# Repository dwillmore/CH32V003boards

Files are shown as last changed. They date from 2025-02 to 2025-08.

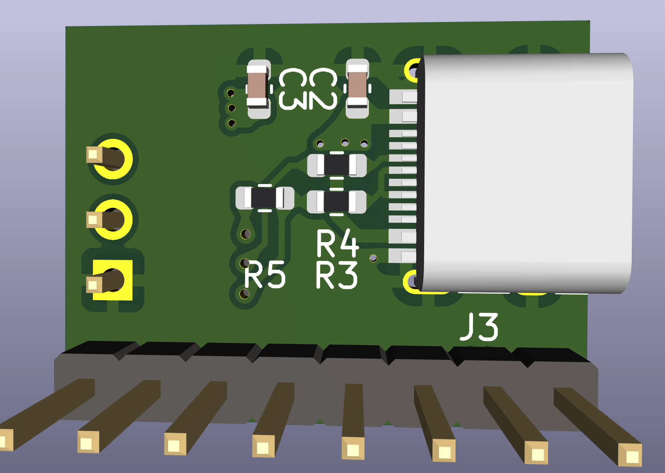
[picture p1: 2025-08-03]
CH32V003J4M6 V4/j4m6_back_3d.jpg

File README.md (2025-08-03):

# CH32V003 dev boards meant for breadboard use.  
They have a all of the chip connections brough out to a SIP header on one side of the board which can be plugged into the outer row of pins on a breadboard--leaving all of the rest of the board available for other components and routing.

All boards have USB-C connections for data and/or power.  The data is connected via two series resistors.  Not populating these allows the pins on the chip to be used for something else.

The on board 3.3V regulator can be left off and bypassed to run the board on Vbus power.  The regulator is used for when the D+/D- lines are connected to use use from the CH32V003 via rv003usb.  

The three pin header is for plugging in a debugger like the funprog or WCH Link-E.  It exposes Vcc, SWD, and GND.

New for V4:
- Change to the popular 1117 style regulator.
- Increase size of decoupling caps to 1206
- Move as many components to the front as possible (not an option on 8 pin) to improve manufacturability
- Add 16 pin variant by popular demand
j4m6_front
f4p6_front
a4m6_front
f4u6_front

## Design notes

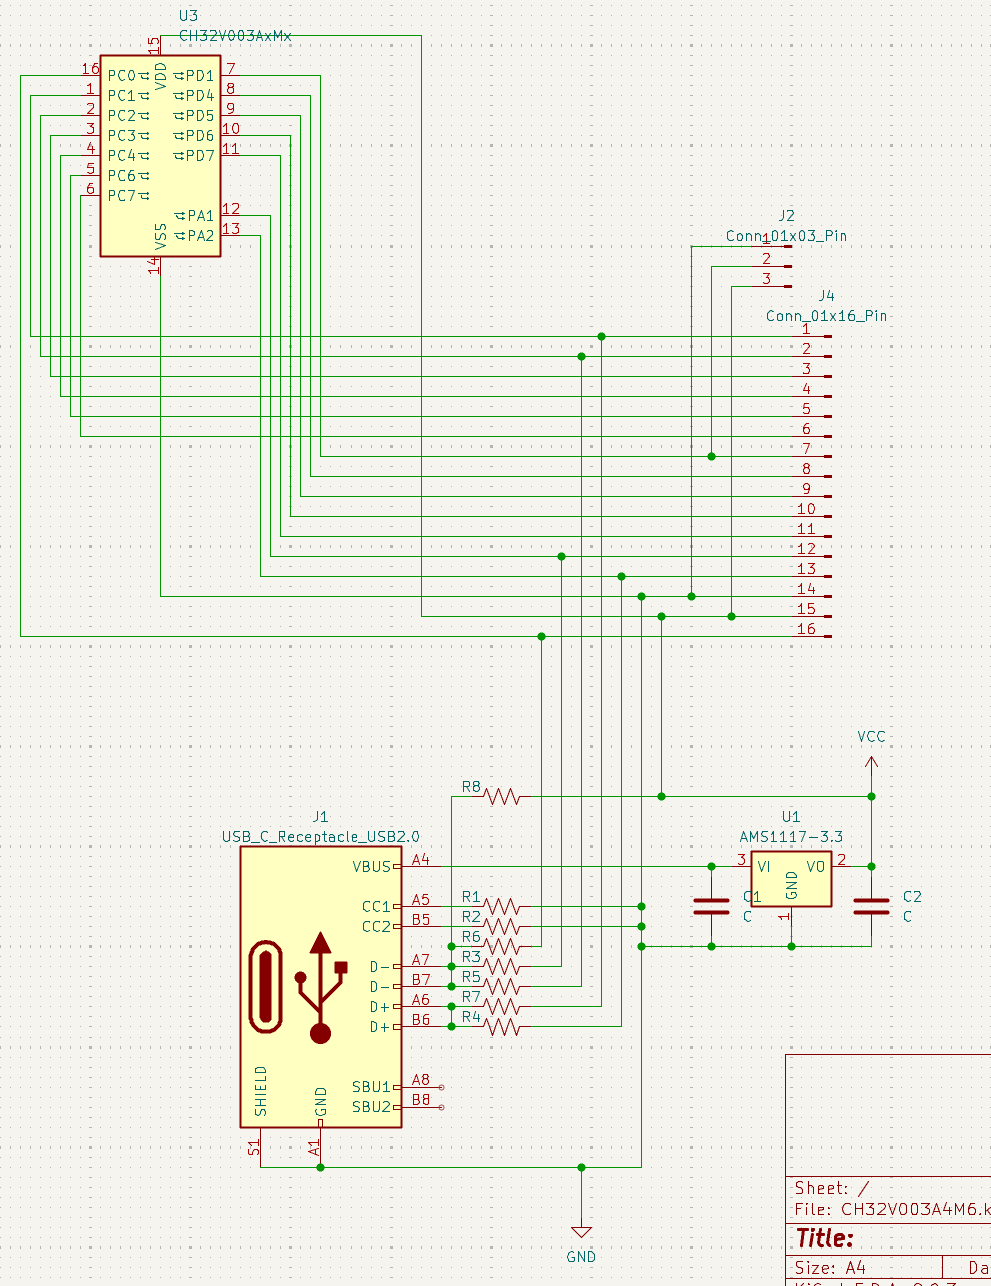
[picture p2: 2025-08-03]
CH32V003A4M6 V4/a4m6_schematic.png

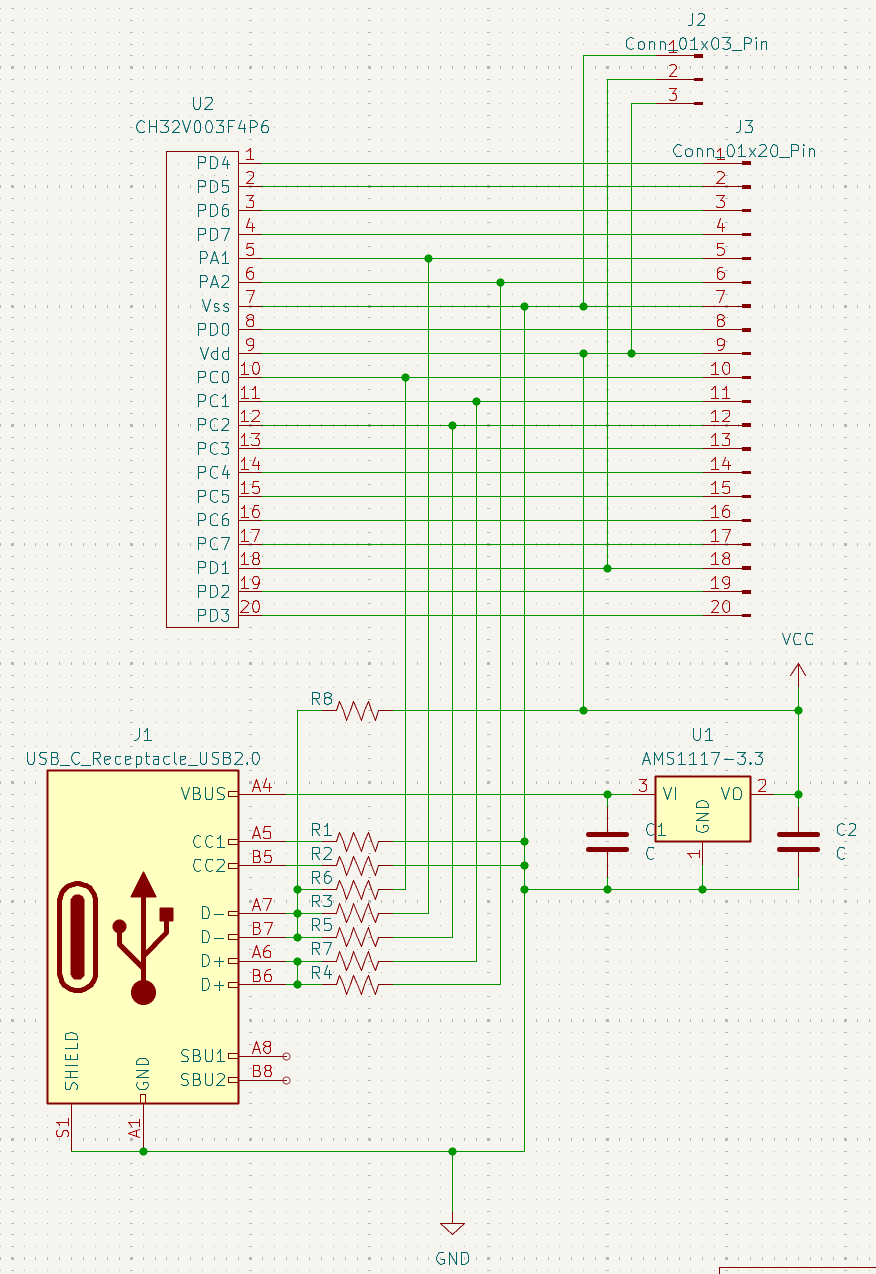
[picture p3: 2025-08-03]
CH32V003F4P6 V4/f4p6_schematic.png

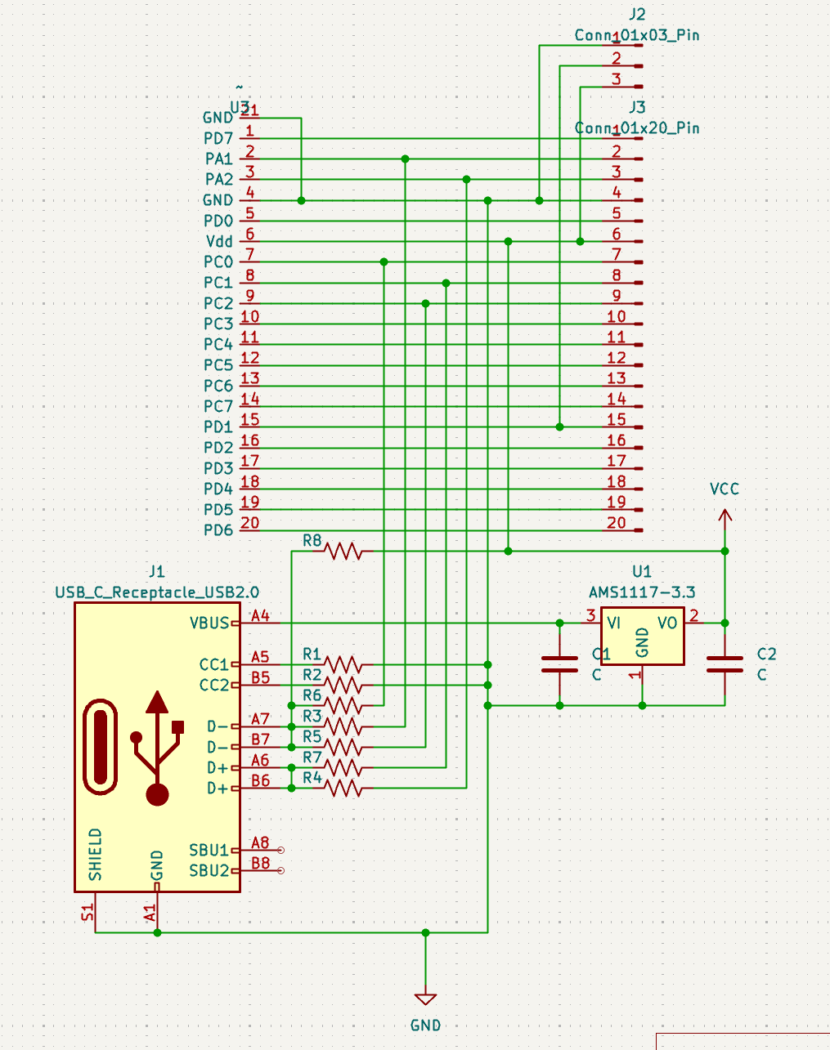
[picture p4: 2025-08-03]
CH32V003F4U6 V4/f4u6_schematic.png

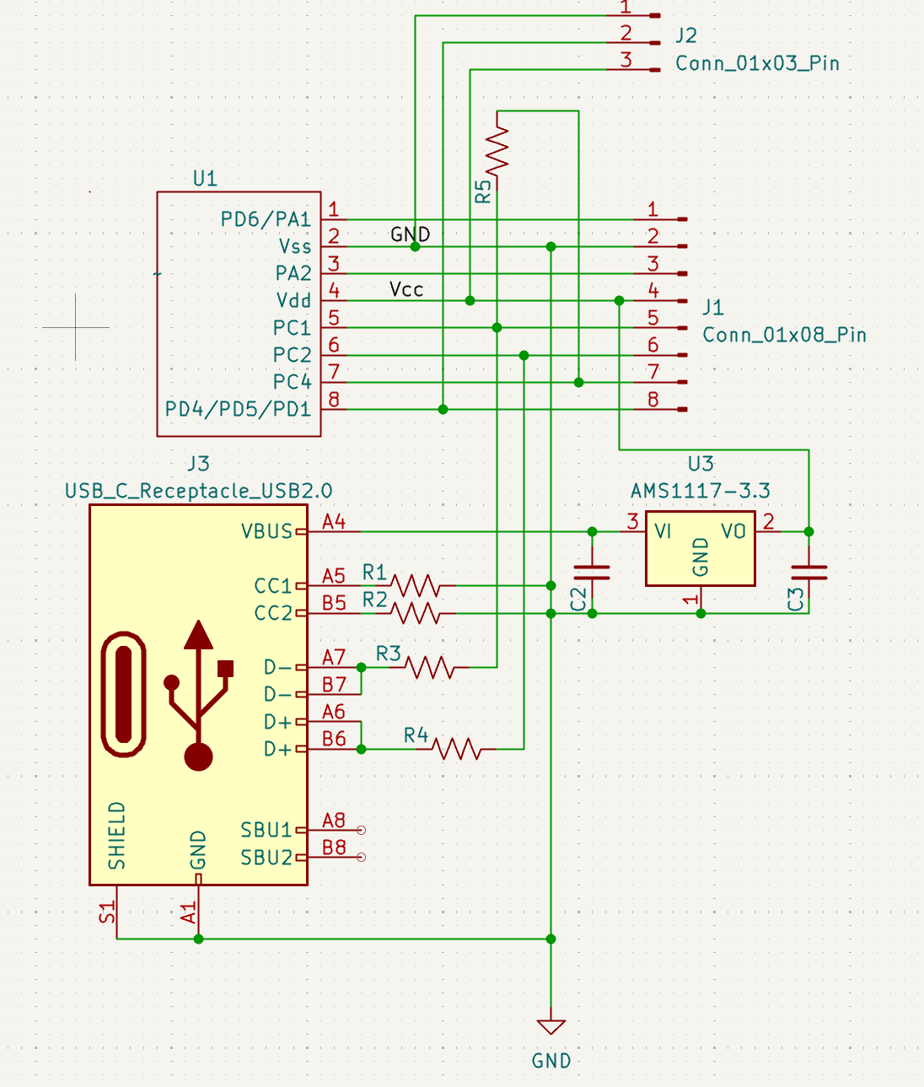
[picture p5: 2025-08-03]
CH32V003J4M6 V4/j4m6_schematic.png

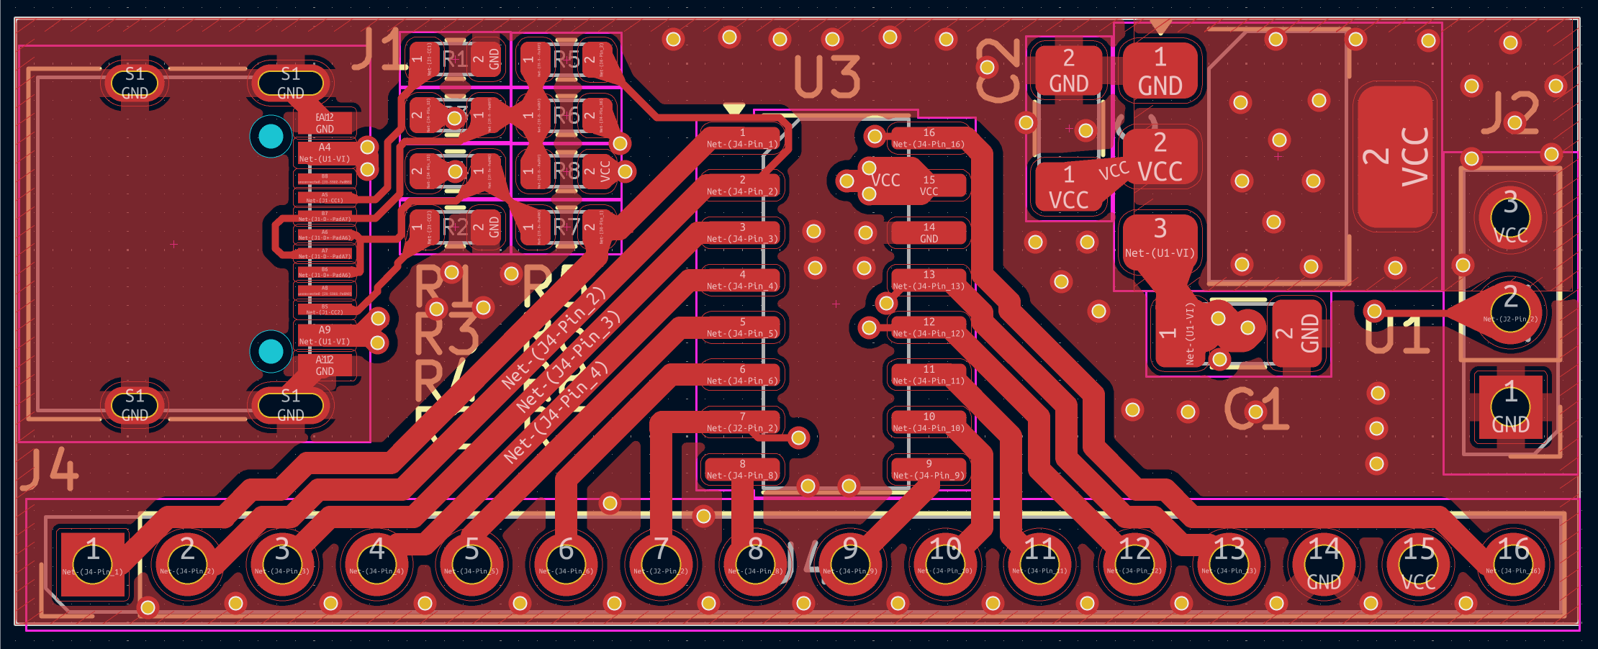
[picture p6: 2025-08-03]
CH32V003A4M6 V4/a4m6_front.png

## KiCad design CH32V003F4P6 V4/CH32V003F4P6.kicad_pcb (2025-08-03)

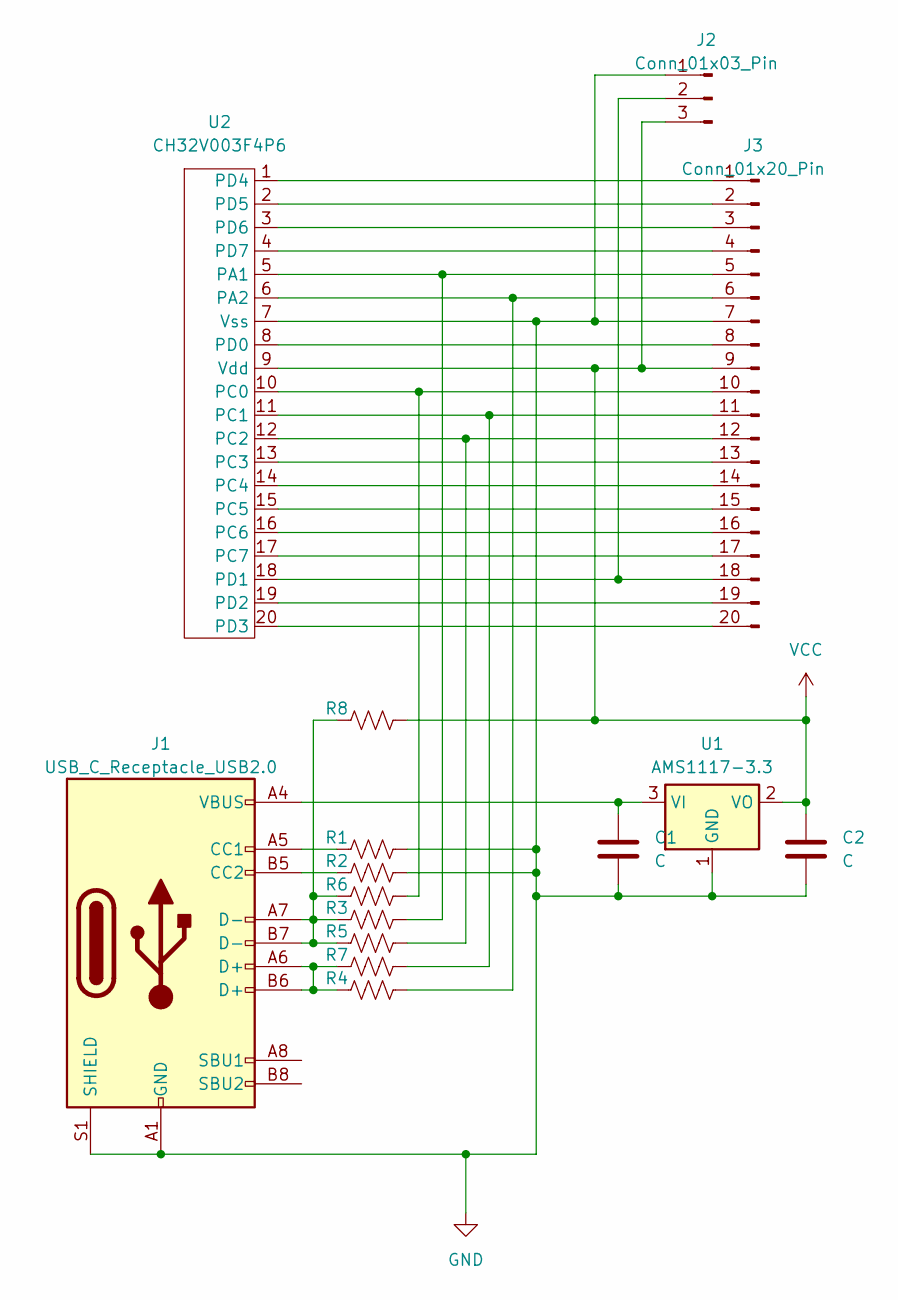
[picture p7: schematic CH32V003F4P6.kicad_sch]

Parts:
C1, C2: C; C_1206_3216Metric_Pad1.33x1.80mm_HandSolder
J1: USB_C_Receptacle_USB2.0; USB_C_Receptacle_HRO_TYPE-C-31-M-12
J2: Conn_01x03_Pin; PinHeader_1x03_P2.54mm_Vertical
J3: Conn_01x20_Pin; PinHeader_1x20_P2.54mm_Vertical
R1, R2, R3, R4, R5, R6, R7, R8: R_US; R_0603_1608Metric
U1: AMS1117-3.3; SOT-223-3_TabPin2
U2: CH32V003F4P6; TSSOP-20_4.4x6.5mm_P0.65mm

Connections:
GND: C1.2, C2.2, J1.A1 (GND), J1.A12 (GND), J1.B1 (GND), J1.B12 (GND), J1.S1 (SHIELD), J2.1, J3.7, R1.2, R2.2, U1.1 (GND), U2.7 (Vss)
unnamed: J1.A5 (CC1), R1.1
unnamed: J1.B5 (CC2), R2.1
unnamed: J1.A6 (D+), J1.B6 (D+), R4.1, R7.1
unnamed: J1.A7 (D-), J1.B7 (D-), R3.1, R5.1, R6.1, R8.1
unnamed: J2.2, J3.18, U2.18 (PD1)
unnamed: J3.1, U2.1 (PD4)
unnamed: J3.2, U2.2 (PD5)
unnamed: J3.3, U2.3 (PD6)
unnamed: J3.4, U2.4 (PD7)
unnamed: J3.5, R3.2, U2.5 (PA1)
unnamed: J3.6, R4.2, U2.6 (PA2)
unnamed: J3.8, U2.8 (PD0)
unnamed: J3.10, R6.2, U2.10 (PC0)
unnamed: J3.11, R7.2, U2.11 (PC1)
unnamed: J3.12, R5.2, U2.12 (PC2)
unnamed: J3.13, U2.13 (PC3)
unnamed: J3.14, U2.14 (PC4)
unnamed: J3.15, U2.15 (PC5)
unnamed: J3.16, U2.16 (PC6)
unnamed: J3.17, U2.17 (PC7)
unnamed: J3.19, U2.19 (PD2)
unnamed: J3.20, U2.20 (PD3)
unnamed: C1.1, J1.A4 (VBUS), J1.A9 (VBUS), J1.B4 (VBUS), J1.B9 (VBUS), U1.3 (VI)
VCC: C2.1, J2.3, J3.9, R8.2, U1.2 (VO), U2.9 (Vdd)

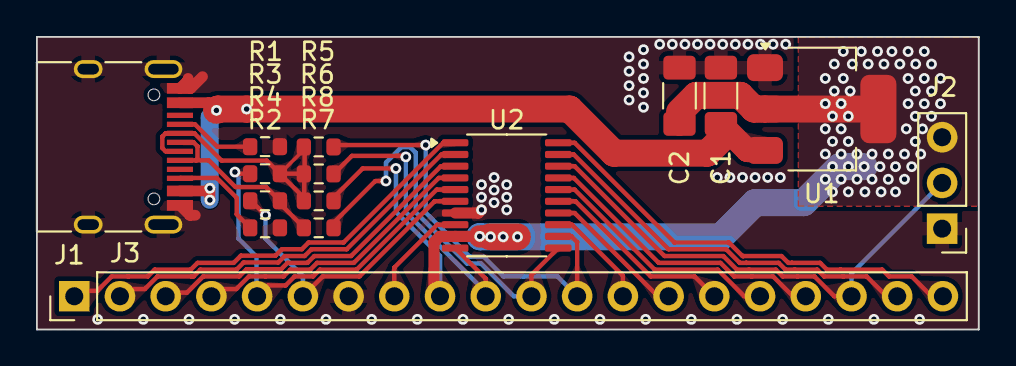
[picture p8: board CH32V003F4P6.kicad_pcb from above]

Board: 2 copper layers, 52.3 x 16.3 mm, 15 parts (0 on the bottom side), 25 nets.

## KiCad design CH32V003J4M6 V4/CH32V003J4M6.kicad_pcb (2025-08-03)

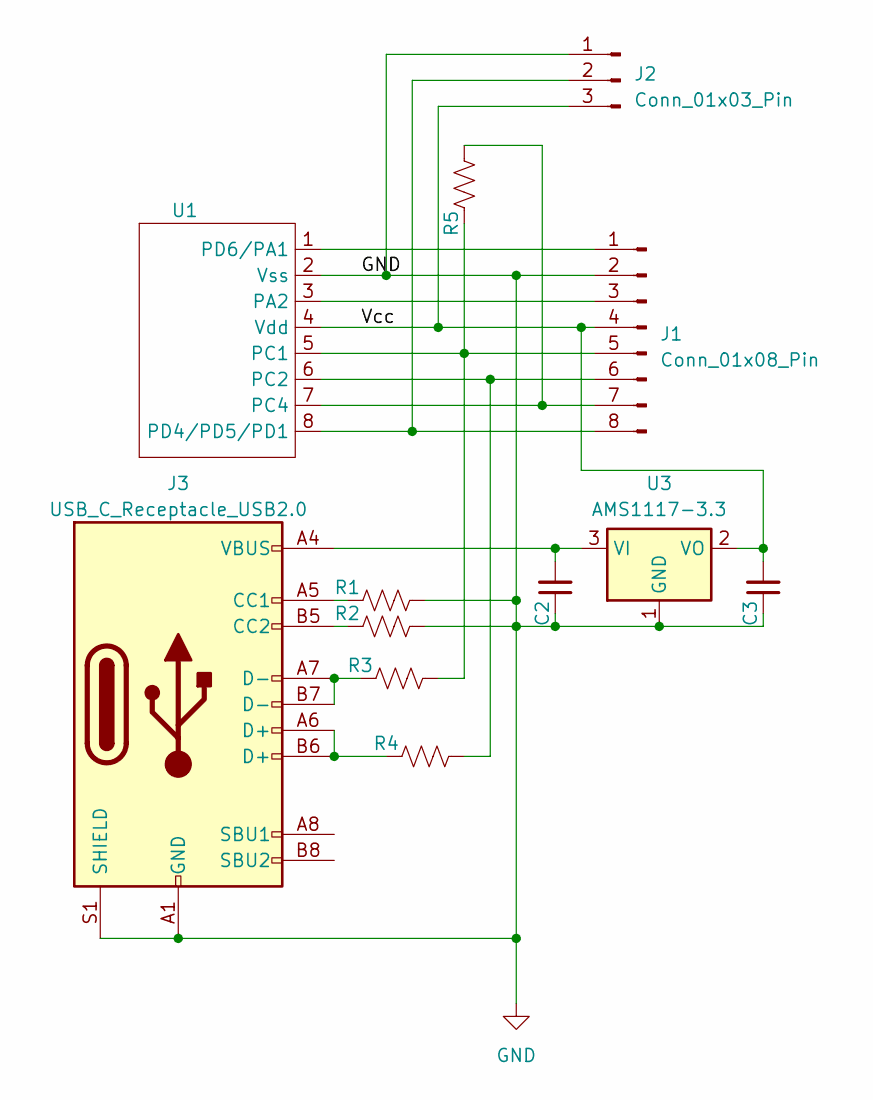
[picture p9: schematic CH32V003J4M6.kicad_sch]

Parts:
C2, C3: C_Small; C_0603_1608Metric
J1: Conn_01x08_Pin; PinHeader_1x08_P2.54mm_Vertical
J2: Conn_01x03_Pin; PinHeader_1x03_P2.54mm_Vertical
J3: USB_C_Receptacle_USB2.0; USB_C_Receptacle_HRO_TYPE-C-31-M-12
R1, R2, R3, R4, R5: R_US; R_0603_1608Metric
U1: SO-8_3.9x4.9mm_P1.27mm
U3: AMS1117-3.3; SOT-223-3_TabPin2

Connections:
/Vcc: C3.2, J1.4, J2.3, U1.4 (Vdd), U3.2 (VO)
GND: C2.1, C3.1, J1.2, J2.1, J3.A1 (GND), J3.A12 (GND), J3.B1 (GND), J3.B12 (GND), J3.S1 (SHIELD), R1.2, R2.2, U1.2 (Vss), U3.1 (GND)
unnamed: J1.1, U1.1 (PD6/PA1)
unnamed: J1.3, U1.3 (PA2)
unnamed: J1.5, R3.2, R5.1, U1.5 (PC1)
unnamed: J1.6, R4.2, U1.6 (PC2)
unnamed: J1.7, R5.2, U1.7 (PC4)
unnamed: J1.8, J2.2, U1.8 (PD4/PD5/PD1)
unnamed: J3.A5 (CC1), R1.1
unnamed: J3.B5 (CC2), R2.1
unnamed: J3.A6 (D+), J3.B6 (D+), R4.1
unnamed: J3.A7 (D-), J3.B7 (D-), R3.1
unnamed: C2.2, J3.A4 (VBUS), J3.A9 (VBUS), J3.B4 (VBUS), J3.B9 (VBUS), U3.3 (VI)

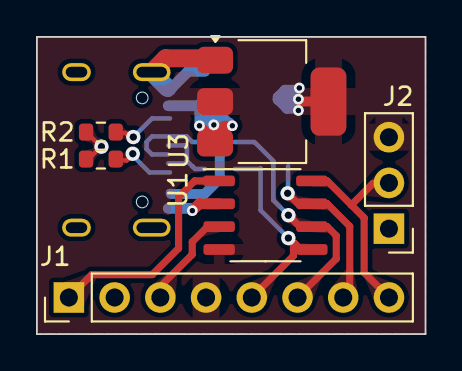
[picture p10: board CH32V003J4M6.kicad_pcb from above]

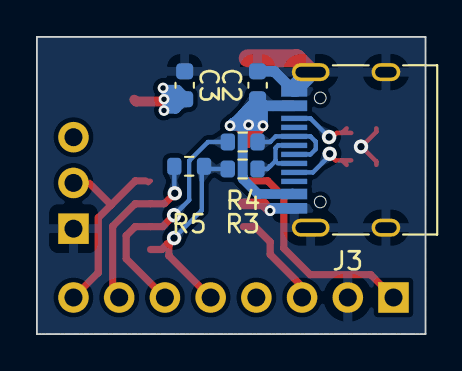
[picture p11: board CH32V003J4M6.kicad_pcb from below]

Board: 2 copper layers, 21.6 x 16.5 mm, 12 parts (6 on the bottom side), 13 nets.

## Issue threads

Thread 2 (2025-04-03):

BOM: Some parts are not clearly identifiable

extrowerk, 2025-04-03:
I'd liek to build the CH32V003J4M6 V3 board, but there is no BOM, and KICAD only lists the part sizes:

```
"Id";"Designator";"Footprint";"Quantity";"Designation";"Supplier and ref";
1;"R1,R2,R4,R3,R5";"R_0603_1608Metric";5;"R_US";;;
2;"J2";"PinHeader_1x03_P2.54mm_Vertical";1;"Conn_01x03_Pin";;;
3;"J1";"PinHeader_1x08_P2.54mm_Vertical";1;"Conn_01x08_Pin";;;
4;"U1";"SO-8_3.9x4.9mm_P1.27mm";1;"~";;;
5;"C1,C2,C3";"C_0603_1608Metric";3;"C_Small";;;
6;"J3";"USB_C_Receptacle_HRO_TYPE-C-31-M-12";1;"USB_C_Receptacle_USB2.0";;;
7;"U2";"SOT-23-5";1;"~";;;
```

Could you please give me the values of the capacitors and resistors?
Do I understand correctly, the SWD pin-header is meant to be sticking out (eg. not meant to be inserted into the breadboard)?

dwillmore, 2025-08-03:
Okay, V4 of the board changes some things and an updated BOM will be forthcoming.

You are correct in that the programming header is not meant to be down into the board.  It should be either a male or female pin header--to fit whatever standard you use on your programmers.  I use sockets (female) because that protects the V+ and GND connections from accidental shorts.

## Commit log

2025-02-15 First upload
    This is my V3 of my single sided CH32V003 boards meant for breadboard use.
    [CH32V003F4P6.kicad_pcb, CH32V003F4P6.kicad_sch, CH32V003F4U6.kicad_pcb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]
2025-08-03 Add V4 board
    [CH32V003A4M6-B_Cu.gbl, CH32V003A4M6-B_Mask.gbs, CH32V003A4M6-B_Paste.gbp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]
2025-08-03 Update README.md
    Add V4 board pics
